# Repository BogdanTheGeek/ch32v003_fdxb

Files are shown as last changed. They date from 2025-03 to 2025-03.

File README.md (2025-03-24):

FDX-B Pet Microchip Reader based on the ch32v003.





# Hardware
The reader coil should be about 5cm in diameter.
Around 50 turns should be enough.

You should aim for an inductance between 400uH to 1mH and a Q of around 8.
Check the Microchip application note in /docs.

The circuit is quite simple, all of the elements are clearly labled in the schematic.

I have included a schematic dedicated for simulating the circuit.



The PCB was designed to be easly for me to etch at home.

# Firmware

## Build
```sh
cd firmware
git submodule update --init --recursive --depth=1
make
```

Alternatively you can define a env variable with the path to your local `ch32fun`:
```sh
export CH32V003FUN=~/ch32fun/ch32fun
```

## How does it work
Timer 1 is used to produce a driving signal for the mosfets that includes deadtime.
An external interrupt is generated on each edge of the signal and this is where most of the decoding happens.

The signal is ecoded with Biphase encoding, meaning that 2 short consecutive periods between signal edges represent a 0 and one longer period represents a 1.

The code uses 2 buffers of 128bits (as 4 x 32bit), one is the working buffer and the other contains the last decoded frame.

Detected bits are loaded from the least significant bit to the most significant bit. The current bit index and a bit mask is used to compare the current state of the buffer to the start condition (1 followed by exactly 10 zeros) as well as to check the control bits. If at any point the buffer doesn't match the expected bit pattern, the bit count and the mask are reset.

Once the working buffer is full, we swap buffers.
We can then parse the raw bit pattern into a struct.

A bunch of optimisations have been made to ensure that the code is as small as possible, but still pretty fast.
Most comparison values have been calculated at compile time and all necesery divisions and modulo opperations have been implemented using bit shifts and bitwise ANDs.

The CRC16K is calculated and verified during the parsing of the bit pattern to minimise copies.

I have included a function that can print a `uint64_t` integer with 0 padding without the use of any decimal division/modulus instructions (which would add about 3k to the binary)

With logs off (but still printing an ID):
```
  FLASH:        2592 B        16 KB     15.82%
    RAM:          60 B         2 KB      2.93%
```

# Resources
 - Nice description of the protocol: https://www.priority1design.com.au/fdx-b_animal_identification_protocol.html
 - Similar project base on Arduino: https://github.com/decrazyo/fdxb
 - FDX-B decoder for sigrok: https://github.com/swdee/fdx-b-decoder

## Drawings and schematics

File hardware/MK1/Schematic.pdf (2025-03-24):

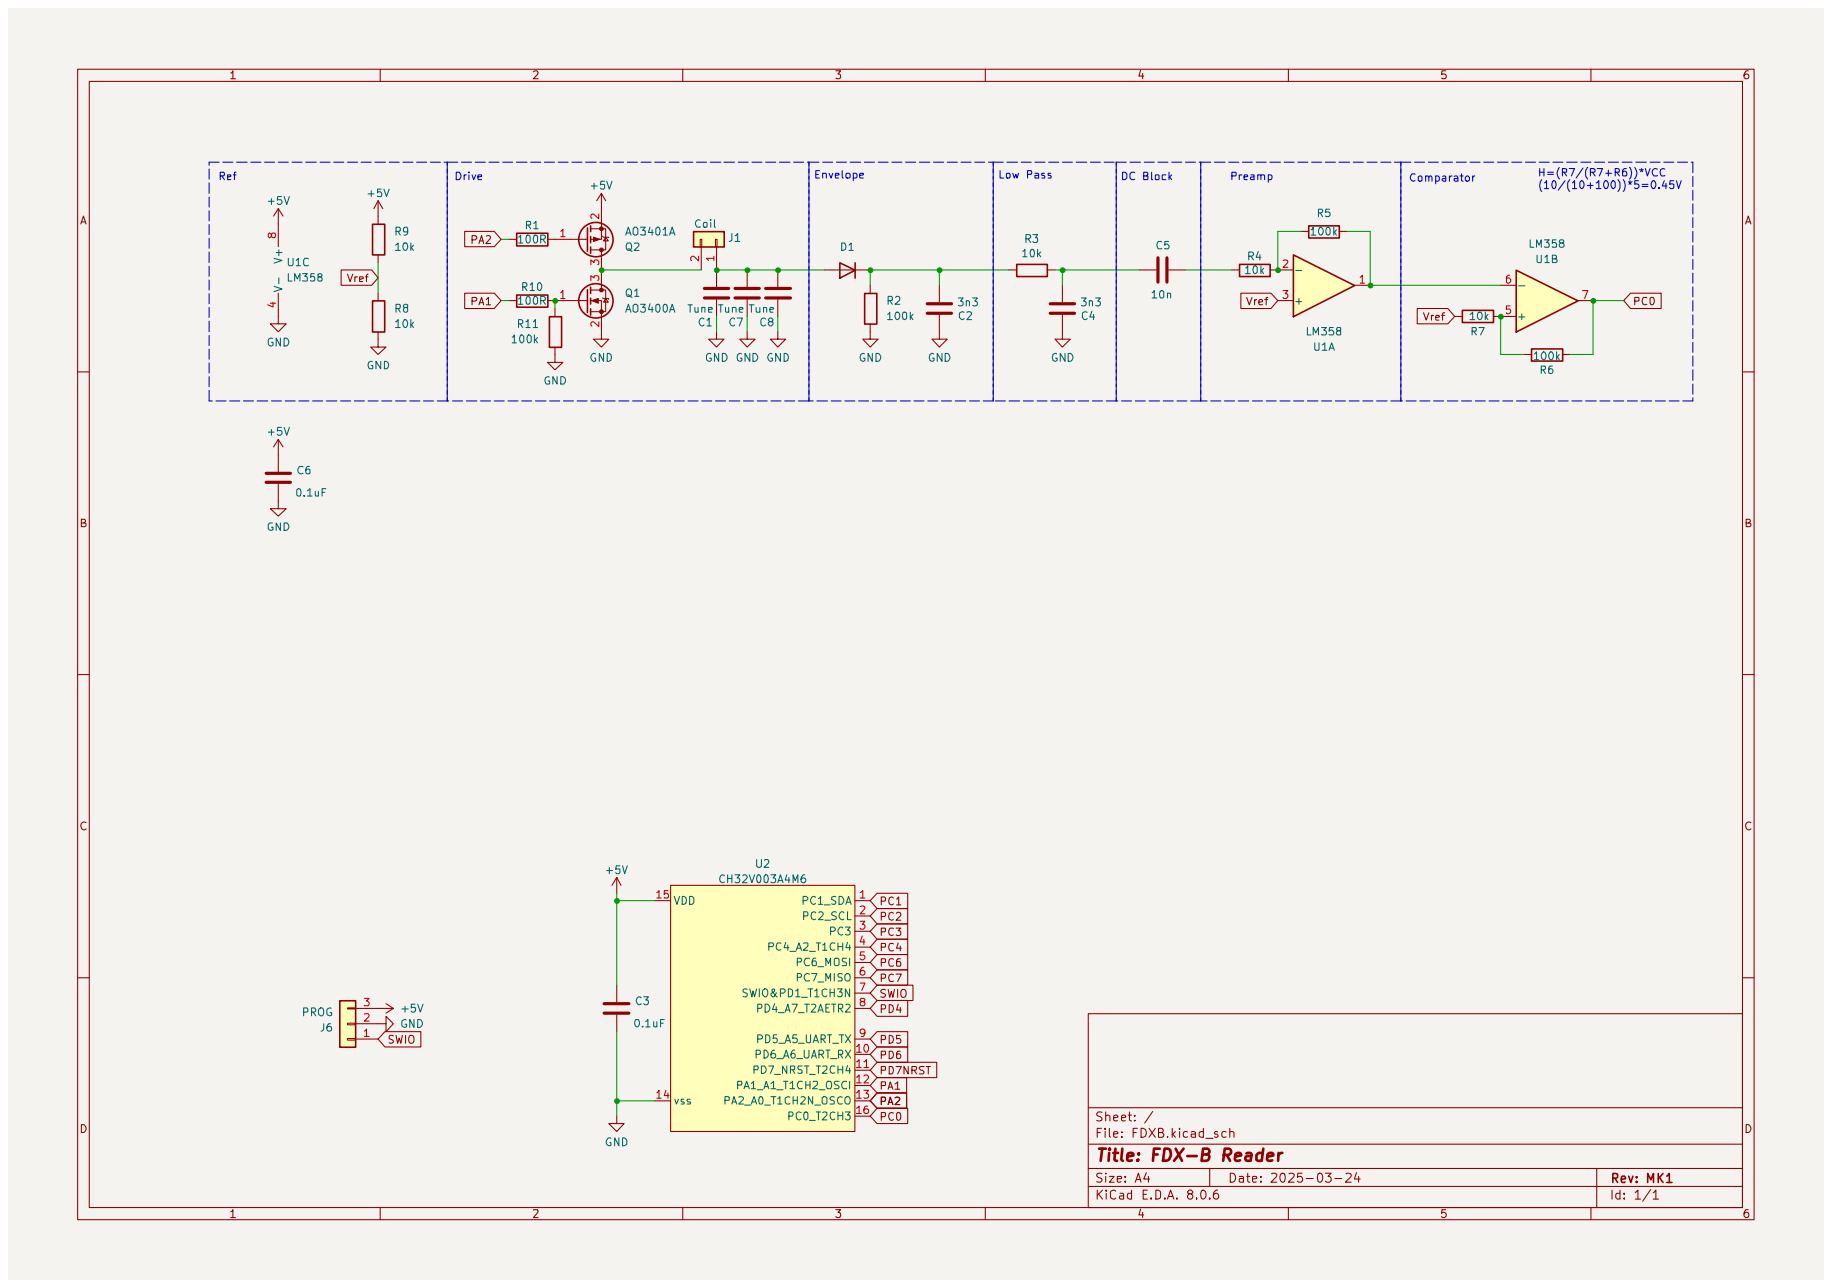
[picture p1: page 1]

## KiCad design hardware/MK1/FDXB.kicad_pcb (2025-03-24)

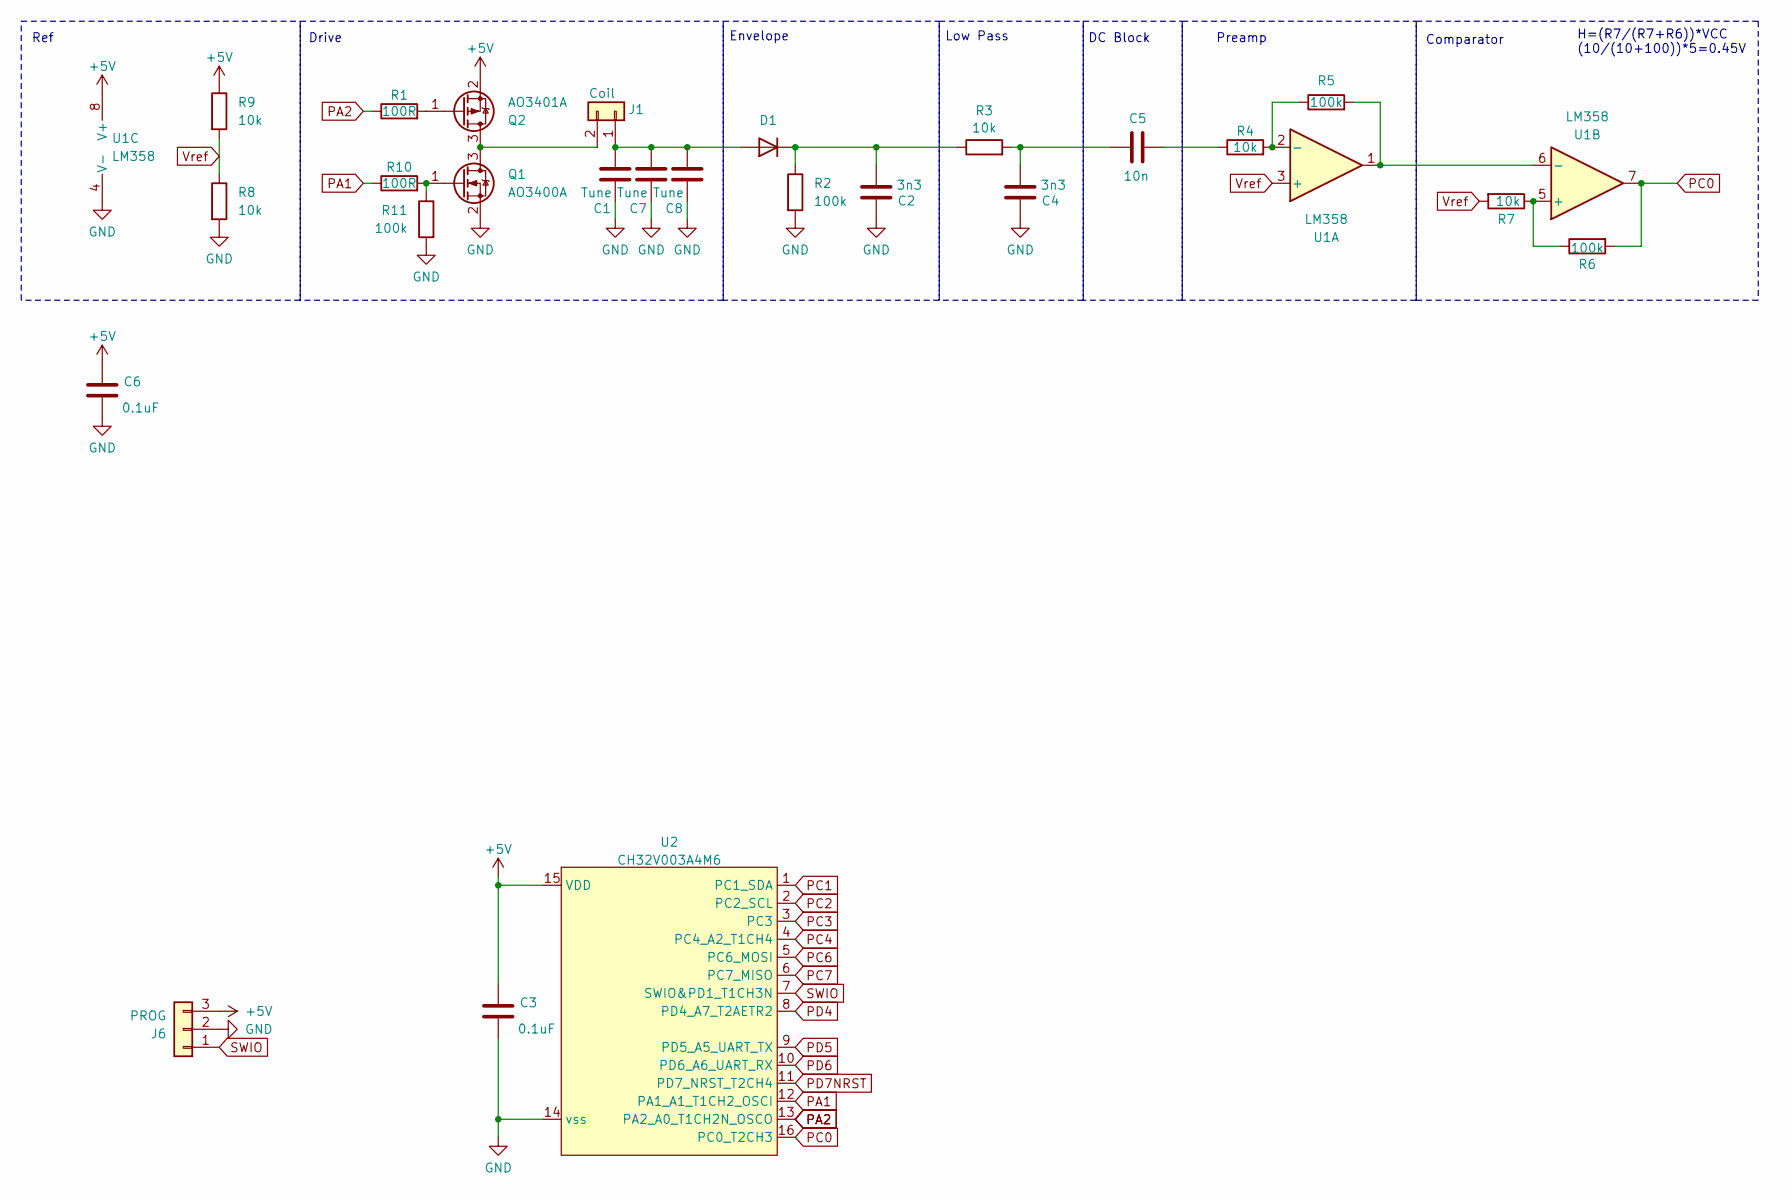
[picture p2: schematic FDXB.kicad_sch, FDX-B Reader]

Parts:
C1, C7, C8: Tune; C_0603_1608Metric_Pad1.08x0.95mm_HandSolder
C2, C4: 3n3; C_0603_1608Metric_Pad1.08x0.95mm_HandSolder
C3, C6: 0.1uF; C_0603_1608Metric_Pad1.08x0.95mm_HandSolder
C5: 10n; C_0603_1608Metric_Pad1.08x0.95mm_HandSolder
D1: D; D_SMA
J1: Coil; PinSocket_1x02_P2.54mm_Vertical
J6: PROG; PinHeader_1x03_P2.54mm_Vertical
Q1: AO3400A; SOT-23
Q2: AO3401A; SOT-23
R1, R10: 100R; R_1206_3216Metric
R2, R5, R6, R11: 100k; R_1206_3216Metric
R3, R4, R7, R8, R9: 10k; R_1206_3216Metric
U1: LM358; SOIC-8_3.9x4.9mm_P1.27mm
U2: CH32V003A4M6; SO-16_3.9x9.9mm_P1.27mm

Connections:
+5V: C3.1, C6.1, J6.3, Q2.2 (S), R9.1, U1.8 (V+), U2.15 (VDD)
GND: C1.1, C2.1, C3.2, C4.1, C6.2, C7.1, C8.1, J6.2, Q1.2 (S), R2.2, R8.2, R11.2, U1.4 (V-), U2.14 (vss)
unnamed: C4.2, C5.2, R3.2
unnamed: C5.1, R4.1
unnamed: C1.2, C7.2, C8.2, D1.2 (A), J1.1
unnamed: C2.2, D1.1 (K), R2.1, R3.1
unnamed: J1.2, Q1.3 (D), Q2.3 (D)
unnamed: Q1.1 (G), R10.2, R11.1
unnamed: Q2.1 (G), R1.2
unnamed: R4.2, R5.1, U1.2 (-)
unnamed: R6.1, R7.1, U1.5 (+)
unnamed: R5.2, U1.1, U1.6 (-)
PA1: R10.1, U2.12 (PA1_A1_T1CH2_OSCI)
PA2: R1.1, U2.13 (PA2_A0_T1CH2N_OSCO)
PC0: R6.2, U1.7, U2.16 (PC0_T2CH3)
PC1: U2.1 (PC1_SDA)
PC2: U2.2 (PC2_SCL)
PC3: U2.3 (PC3)
PC4: U2.4 (PC4_A2_T1CH4)
PC6: U2.5 (PC6_MOSI)
PC7: U2.6 (PC7_MISO)
PD4: U2.8 (PD4_A7_T2AETR2)
PD5: U2.9 (PD5_A5_UART_TX)
PD6: U2.10 (PD6_A6_UART_RX)
PD7NRST: U2.11 (PD7_NRST_T2CH4)
SWIO: J6.1, U2.7 (SWIO&PD1_T1CH3N)
Vref: R7.2, R8.1, R9.2, U1.3 (+)

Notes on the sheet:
H=(R7/(R7+R6))*VCC (10/(10+100))*5=0.45V
Drive
Preamp
Envelope
Ref
DC Block
Comparator
Low Pass

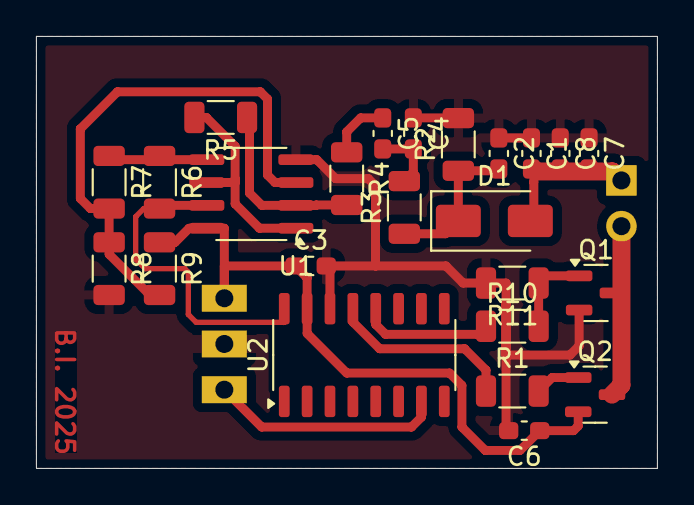
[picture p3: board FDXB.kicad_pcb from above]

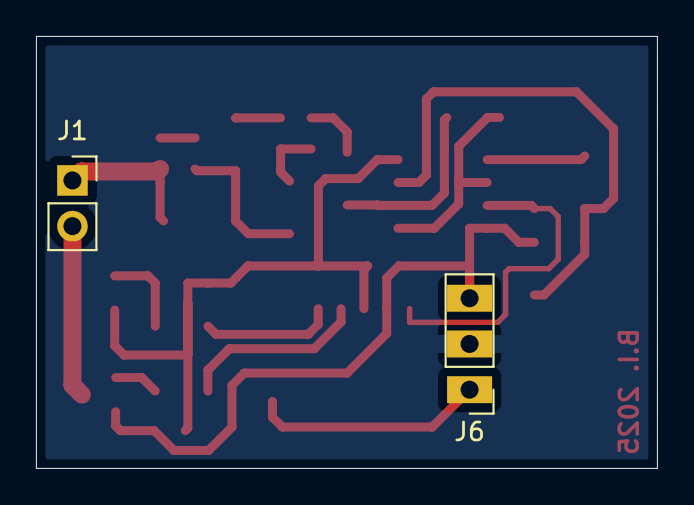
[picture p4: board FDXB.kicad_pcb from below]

Board: 2 copper layers, 34.5 x 24.0 mm, 26 parts (2 on the bottom side), 17 nets.

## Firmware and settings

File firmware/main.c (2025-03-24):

//------------------------------------------------------------------------------
//       Filename: main.c
//------------------------------------------------------------------------------
//       Bogdan Ionescu (c) 2025
//------------------------------------------------------------------------------
//       Purpose : Application entry point
//------------------------------------------------------------------------------
//       Notes :
//------------------------------------------------------------------------------

//------------------------------------------------------------------------------
// Module includes
//------------------------------------------------------------------------------
#include <inttypes.h>
#include <stdbool.h>
#include <stdint.h>
#include <string.h>

#include <ch32fun.h>

#include "fdxb.h"
#include "log.h"

//------------------------------------------------------------------------------
// Module constant defines
//------------------------------------------------------------------------------
#define TAG "main"

//------------------------------------------------------------------------------
// External variables
//------------------------------------------------------------------------------

//------------------------------------------------------------------------------
// External functions
//------------------------------------------------------------------------------

//------------------------------------------------------------------------------
// Module type definitions
//------------------------------------------------------------------------------

//------------------------------------------------------------------------------
// Module static variables
//------------------------------------------------------------------------------
static volatile uint32_t s_systickCount = 0;

//------------------------------------------------------------------------------
// Module static function prototypes
//------------------------------------------------------------------------------
static void SysTick_Init(void);
static void WDT_Init(uint16_t reload_val, uint8_t prescaler);
static void WDT_Pet(void);

//------------------------------------------------------------------------------
// Module externally exported functions
//------------------------------------------------------------------------------

/**
 * @brief  Application entry point
 * @param  None
 * @return None
 */
int main(void)
{
    SystemInit();
    SysTick_Init();

    const bool debuggerAttached = !WaitForDebuggerToAttach(1000);
    if (debuggerAttached)
    {
        LOG_Init(eLOG_LEVEL_INFO, (uint32_t *)&s_systickCount);
    }
    else
    {
        LOG_Init(eLOG_LEVEL_NONE, (uint32_t *)&s_systickCount);
    }

    WDT_Init(0x0FFF, IWDG_Prescaler_128);

    FDX_B_Init();

    uint32_t lastTick = s_systickCount;
    while (1)
    {

        if (FDX_B_Available())
        {
            FDX_B_t tag;
            FDX_B_Read(&tag);

            if (!tag.valid)
            {
                LOGE(TAG, "Invalid Tag");
            }
            else
            {
                char idStr[16];
                FDX_B_ID_ToString(&tag, idStr);
                puts("ID:");
                puts(idStr);
                puts("Animal:");
                puts(tag.animal ? "Yes" : "No");
            }
        }

        // Pet the watchdog every second
        if (s_systickCount - lastTick > 1000)
        {
            lastTick = s_systickCount;
            WDT_Pet();
            LOGI(TAG, "Looking for tags");
        }
    }
}

//------------------------------------------------------------------------------
// Module static functions
//------------------------------------------------------------------------------

/**
 * @brief  Enable the SysTick module
 * @param  None
 * @return None
 */
static void SysTick_Init(void)
{
    // Disable default SysTick behavior
    SysTick->CTLR = 0;

    // Enable the SysTick IRQ
    NVIC_EnableIRQ(SysTicK_IRQn);

    // Set the tick interval to 1ms for normal op
    SysTick->CMP = (FUNCONF_SYSTEM_CORE_CLOCK / 1000) - 1;

    // Start at zero
    SysTick->CNT = 0;
    s_systickCount = 0;

    // Enable SysTick counter, IRQ, HCLK/1
    SysTick->CTLR = SYSTICK_CTLR_STE | SYSTICK_CTLR_STIE | SYSTICK_CTLR_STCLK;
}

/**
 * @brief  Initialize the watchdog timer
 * @param reload_val - the value to reload the counter with
 * @param prescaler - the prescaler to use
 * @return None
 */
static void WDT_Init(uint16_t reload_val, uint8_t prescaler)
{
    IWDG->CTLR = 0x5555;
    IWDG->PSCR = prescaler;

    IWDG->CTLR = 0x5555;
    IWDG->RLDR = reload_val & 0xfff;

    IWDG->CTLR = 0xCCCC;
}

/**
 * @brief  Pet the watchdog timer
 * @param  None
 * @return None
 */
static void WDT_Pet(void)
{
    IWDG->CTLR = 0xAAAA;
}

/**
 * @brief  SysTick interrupt handler
 * @param  None
 * @return None
 * @note   __attribute__((interrupt)) syntax is crucial!
 */
void SysTick_Handler(void) __attribute__((interrupt));
void SysTick_Handler(void)
{
    // Set the next interrupt to be in 1/1000th of a second
    SysTick->CMP += (FUNCONF_SYSTEM_CORE_CLOCK / 1000);

    // Clear IRQ
    SysTick->SR = 0;

    // Update counter
    s_systickCount++;
}

//------------------------------------------------------------------------------
//------------------------------------------------------------------------------
//------------------------------------------------------------------------------

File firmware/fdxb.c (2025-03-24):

//------------------------------------------------------------------------------
//       Filename: fdxb.c
//------------------------------------------------------------------------------
//       Bogdan Ionescu (c) 2025
//------------------------------------------------------------------------------
//       Purpose : Implements the FDX-B module interface
//------------------------------------------------------------------------------
//       Notes : None
//------------------------------------------------------------------------------

//------------------------------------------------------------------------------
// Module includes
//------------------------------------------------------------------------------
#include <ch32fun.h>

#include "fdxb.h"
#include "log.h"

//------------------------------------------------------------------------------
// Module constant defines
//------------------------------------------------------------------------------
#define TAG "FDX-B"

#ifndef US_TO_TICKS
#define US_TO_TICKS(us) ((us) * (FUNCONF_SYSTEM_CORE_CLOCK / 1000000))
#endif

#ifndef BITMASK
#define BITMASK(x) ((1 << (x)) - 1)
#endif

#if CONFIG_INLINE_RIGHT_SHIFT
#define RIGHT_SHIFT(data, shift)                                                             \
    do                                                                                       \
    {                                                                                        \
        (data)[0] = ((data)[0] >> (shift)) | ((data)[1] & BITMASK(shift)) << (32 - (shift)); \
        (data)[1] = ((data)[1] >> (shift)) | ((data)[2] & BITMASK(shift)) << (32 - (shift)); \
        (data)[2] = ((data)[2] >> (shift)) | ((data)[3] & BITMASK(shift)) << (32 - (shift)); \
        (data)[3] = ((data)[3] >> (shift));                                                  \
    } while (0)
#else
static void RIGHT_SHIFT(uint32_t data[4], size_t shift)
{
    data[0] = (data[0] >> shift) | (data[1] & BITMASK(shift)) << (32 - shift);
    data[1] = (data[1] >> shift) | (data[2] & BITMASK(shift)) << (32 - shift);
    data[2] = (data[2] >> shift) | (data[3] & BITMASK(shift)) << (32 - shift);
    data[3] = (data[3] >> shift);
}
#endif

//------------------------------------------------------------------------------
// External variables
//------------------------------------------------------------------------------

//------------------------------------------------------------------------------
// External functions
//------------------------------------------------------------------------------

//------------------------------------------------------------------------------
// Module type definitions
//------------------------------------------------------------------------------

//------------------------------------------------------------------------------
// Module static variables
//------------------------------------------------------------------------------
static volatile uint32_t s_buffer[2][4] = {0};
static volatile int s_activeBuffer = 0;
static volatile bool s_tagAvailable = 0;

static volatile size_t s_bitCount = 0;
static volatile uint32_t s_bitMask = 0;
static volatile size_t s_bitCountMax = 0;
static volatile uint32_t s_lastPinChange = 0;
static volatile bool s_lastLastWasShort = false;

// Bits I want to check
static const uint32_t c_checkBitsMask[4] = {
    0b00100000000100000000111111111111,
    0b00000001000000001000000001000000,
    0b00010000000010000000010000000010,
    0b00000000100000000100000000100000,
};

// Values for bits to check
static const uint32_t c_validBits[4] = {
    0b00100000000100000000100000000001,
    0b00000001000000001000000001000000,
    0b00010000000010000000010000000010,
    0b00000000100000000100000000100000,
};

//------------------------------------------------------------------------------
// Module static function prototypes
//------------------------------------------------------------------------------
static void SetDeadTime(TIM_TypeDef *timer, uint16_t deadtime);
static void PWM_Init(void);
static void InputCapture_Init(void);
static void SetupOpAmp(int channel);
static uint16_t CRC16K(uint16_t crc, const uint8_t val);
static char mod10(uint64_t *u);
static void Load(FDX_B_t *tag, uint32_t raw[4]);

//------------------------------------------------------------------------------
// Module externally exported functions
//------------------------------------------------------------------------------

/**
 * @brief  Initialize the FDX-B module
 * @param  None
 * @return None
 */
void FDX_B_Init(void)
{
    PWM_Init();
    Delay_Ms(100);
    InputCapture_Init();
}

/**
 * @brief  Check if a tag is available to read
 * @param  None
 * @return true if a tag is available
 */
bool FDX_B_Available(void)
{
    return s_tagAvailable;
}

/**
 * @brief  Read the tag
 * @param[out] tag - The tag to read into
 * @return None
 */
void FDX_B_Read(FDX_B_t *tag)
{
    // Disable the interrupt while we read the tag
    NVIC_DisableIRQ(EXTI7_0_IRQn);

    // Load from the inactive buffer
    Load(tag, (uint32_t *)s_buffer[s_activeBuffer ^ 1]);
    s_tagAvailable = false;

    NVIC_EnableIRQ(EXTI7_0_IRQn);
}
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
